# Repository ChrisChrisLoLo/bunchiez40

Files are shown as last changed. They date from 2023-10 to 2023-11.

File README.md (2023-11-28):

# bunchiez40
An experimental ultraportable keyboard that uses mouse switches to achieve a compact form factor while still being viable as a daily use keyboard. Board can be hand soldered, and case can be 3D printed or CNC'd.

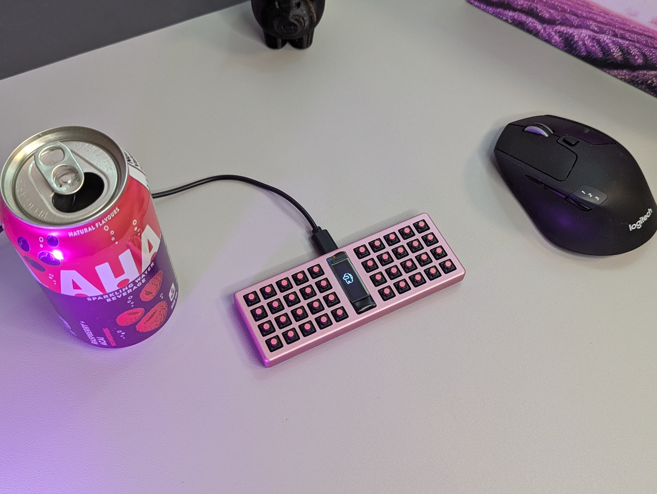
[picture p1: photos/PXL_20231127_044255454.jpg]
a photo of a bunchiez40


Has science gone too far?

# Status
v0.0 PCBs confirmed to be working! Happy to open up this project for others to play with

# About
I hit the limit as how small I could go with choc switches. I found that kailh mute switches are an ideal small form factor alternative in terms of their size, durability, and actuation force. To make this board more accessible to build at home, it uses a rp2040-zero board that can be soldered on.

More details about my research on mouse switches and experience with the bunchiez40 can be found here: https://chrischrislolo.github.io/orthoLabLogs/bunchiez40-how-i-built-a-keyboard-using-mouse-switches.html

Case files include STLs, STEP files, as well as source OpenSCAD files that can be modified. The OpenSCAD models do not have fillets on them

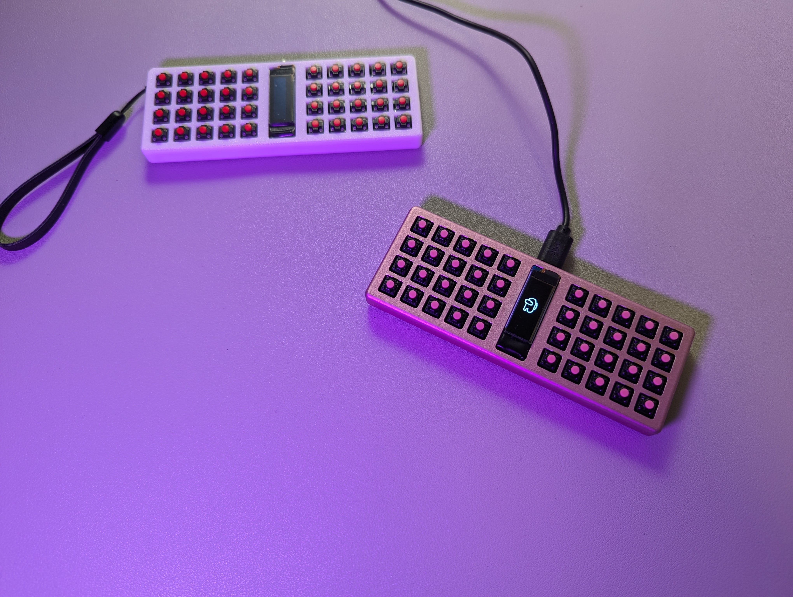
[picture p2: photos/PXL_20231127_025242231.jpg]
some bunchiez40


# Case
The case files can be found in the `case` directory. The particular files you'll want are the `case_holes` file for the top part of the case, and the `case_holes_floor` file for the bottom part. CNC and 3DP works with the top part of the case, and I chose to 3DP my case bottom.

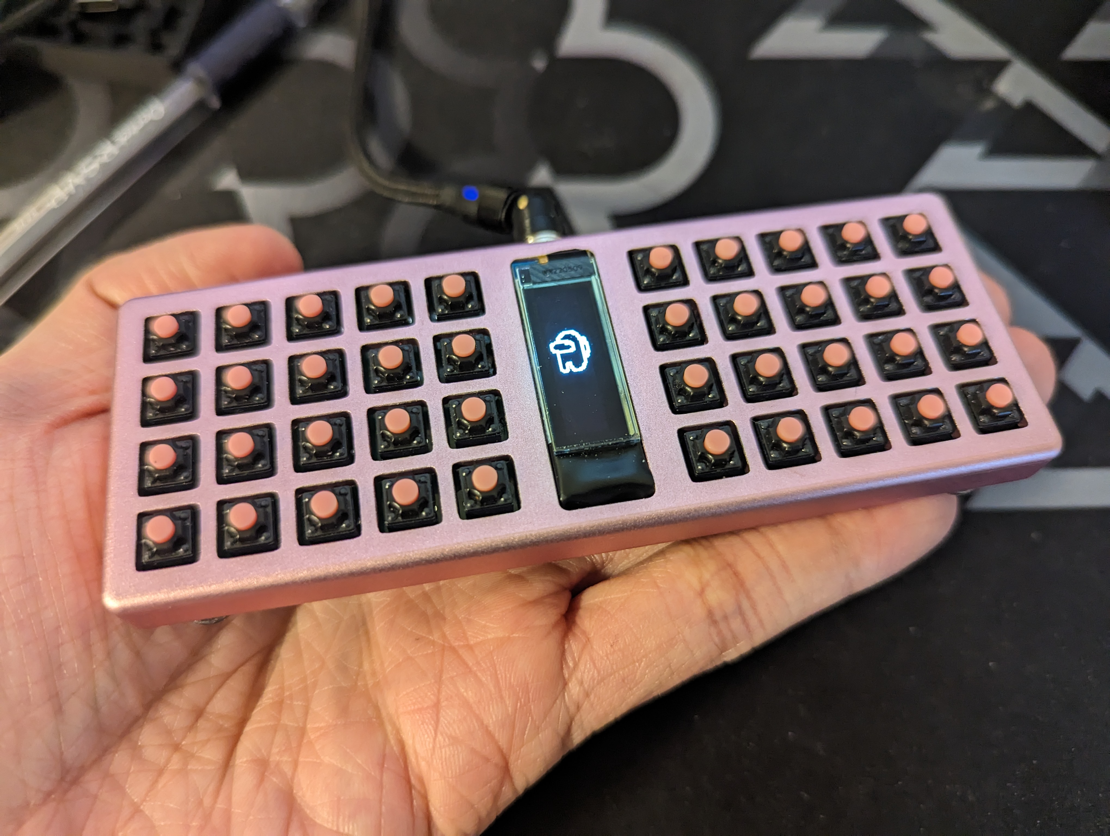
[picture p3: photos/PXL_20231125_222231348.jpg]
bunchiez40 in my hand


## PCB
You can find the PCB source files in the `pcb` folder. The BOM files can be found in this folder.

## Directory Structure
- `case`
    You can find the files you need in this folder to print out a case for the keyboard
- `drafts`
    Stores any KLE or intermediate information used in making the case
- `outlines`
    Outlines used to create the case and pcb
- `pcb`
    Kicad project relating to the project
   
## BOM
- 1 PCB
- 1 Aluminum CNC upper case or 3DP upper case
- 1 lower case. I 3D printed mine
- 16 3mm M1.6 screws (go for flathead for a flush fit, though other head types should also work)
- 4-8 (ideally 8) 1-2mm bumpons (something like Sj5302 is a good place to start)
- 1 0.91 inch OLED
- 1 rp2040-zero pcb
- 40 Kailh/Huano 7.3mm mute switches (ideally with some spares)
- 40 LL4148 diodes (ideally with some spares)

## Assembly
Build guide coming soon. For now, hopefully the footprints make it clear as to what should go where. Note that the rp2040-zero should be placed in such a way that the MCU is on "top" of the pcb when the assembly is face up, like such.
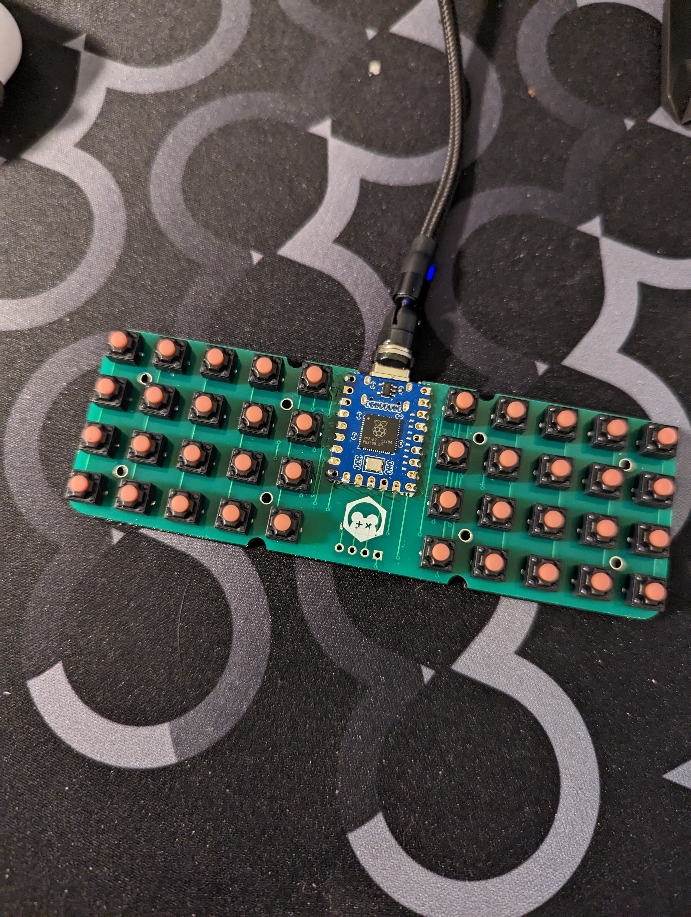
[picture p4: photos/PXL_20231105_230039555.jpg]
photo of assembly


Once all parts have been assembled, the board can be screwed onto the top of the case with 8 screws.

The firmware should then be flashed onto the board.

The bottom of the board can then be screwed to the case. My recommendation is to put two bumpons on each corner of the bottom of the case, one above the screw and one beside the screw. This helps maximize stability.  

## Firmware
QMK Firmware can be found here
https://github.com/ChrisChrisLoLo/vial-qmk/tree/sporewoh/keyboards/sporewoh/bunchiez40

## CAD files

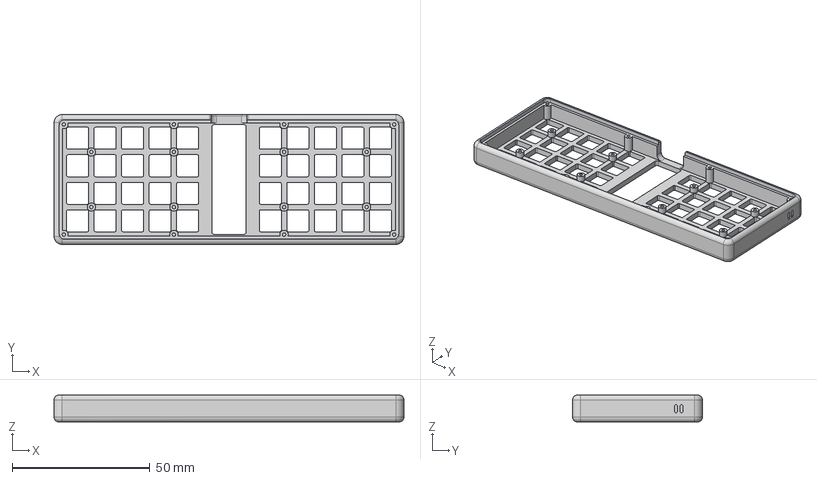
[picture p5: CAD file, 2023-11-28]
case/bunchiez40 v10.step
127.2 x 47.2 x 9.80 mm

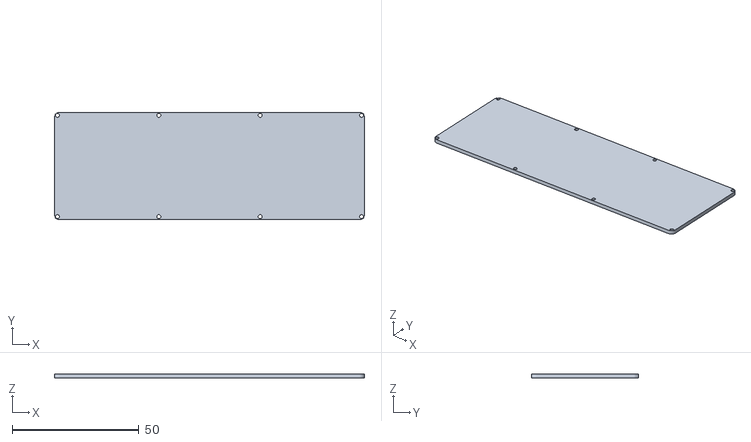
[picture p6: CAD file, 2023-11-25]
case/experimental_junk/case_bottom.stl
122.3 x 42.3 x 1.57

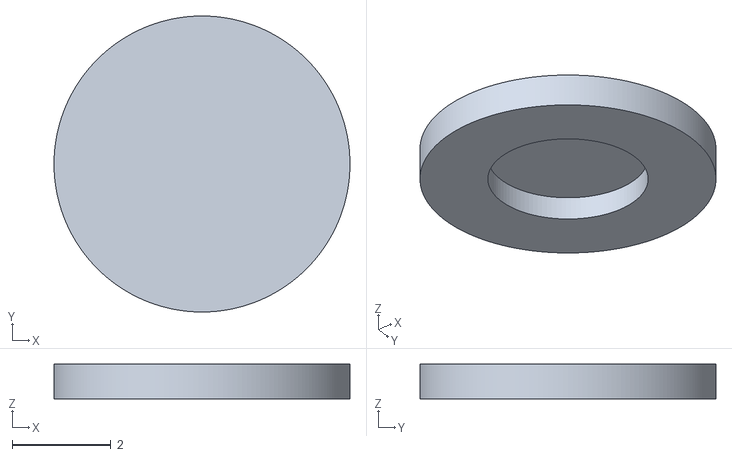
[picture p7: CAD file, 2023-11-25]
case/keys/keycap.stl
6.00 x 6.00 x 0.7

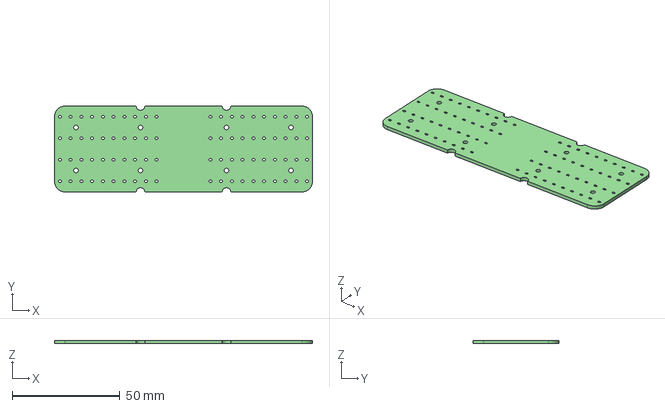
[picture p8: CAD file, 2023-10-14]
pcb/buinchiez40/buinchiez40.step
120.0 x 40.0 x 1.60 mm

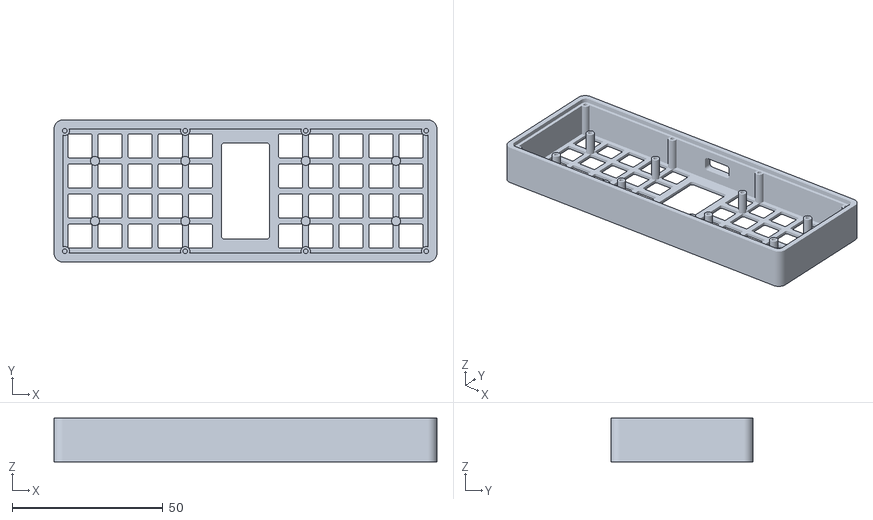
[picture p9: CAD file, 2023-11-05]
case/experimental_junk/case_holes_membrane_case.stl
127.2 x 47.2 x 14.6

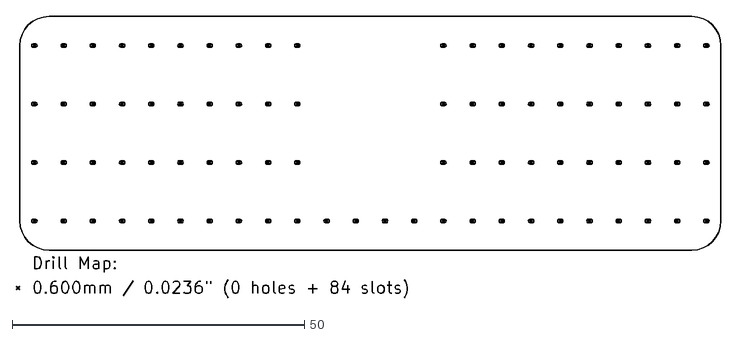
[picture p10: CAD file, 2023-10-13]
pcb/buinchiez40/buinchiez40-PTH-drl-drl_map.dxf
120.7 x 48.1

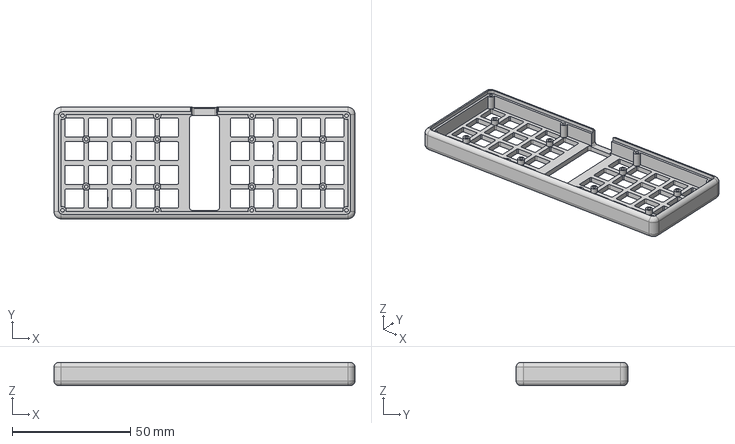
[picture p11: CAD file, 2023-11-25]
case/case_holes_top.step
127.2 x 47.2 x 9.80 mm

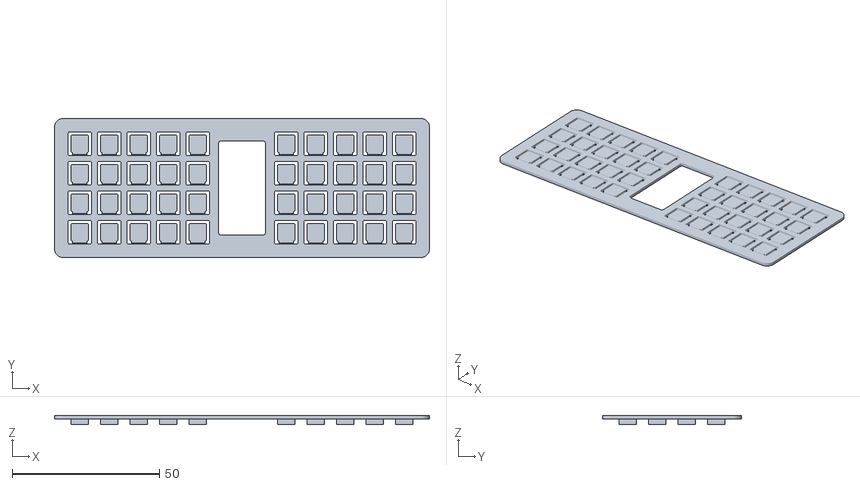
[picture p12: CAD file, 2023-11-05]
case/experimental_junk/case_hinge.stl
127.2 x 47.2 x 3.00

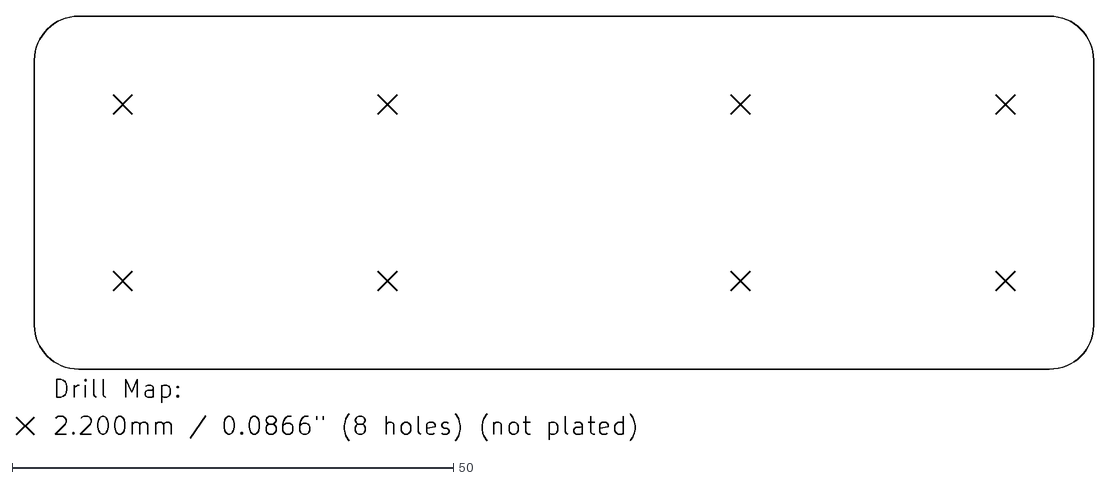
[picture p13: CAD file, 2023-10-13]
pcb/buinchiez40/buinchiez40-NPTH-drl-drl_map.dxf
122.0 x 48.1

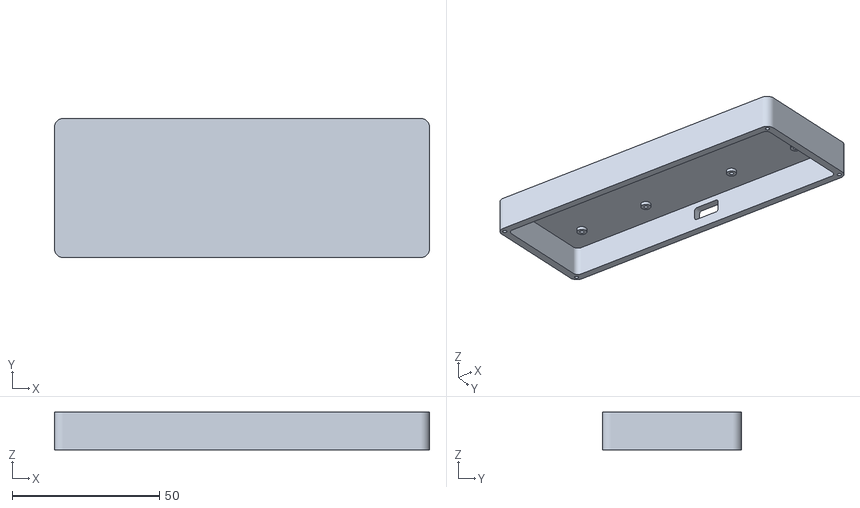
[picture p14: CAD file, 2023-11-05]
case/experimental_junk/case_hinge_bottom.stl
127.2 x 47.2 x 12.8

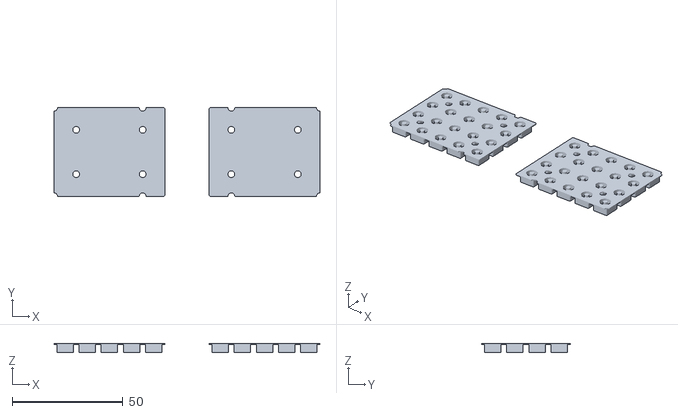
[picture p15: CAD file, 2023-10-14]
case/experimental_junk/case_holes_membrane_sheet.stl
120.0 x 40.0 x 4.00

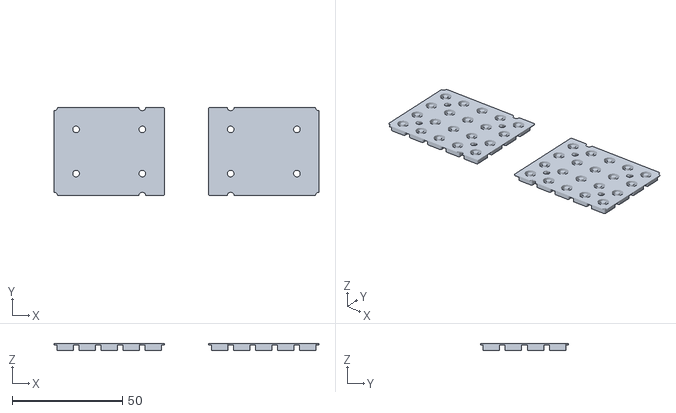
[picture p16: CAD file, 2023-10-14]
case/experimental_junk/case_holes_membrane.stl
120.0 x 40.0 x 3.00

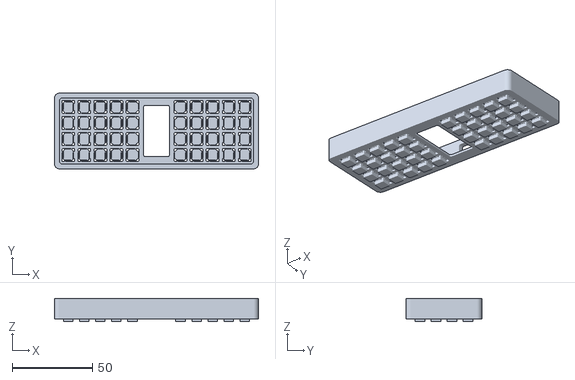
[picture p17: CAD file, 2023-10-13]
case/experimental_junk/case_spring.stl
127.2 x 47.2 x 14.6

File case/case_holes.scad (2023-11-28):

// units are in mm

$fa = 0.1;
$fs = 0.1;

//// MODULES 
module rounding2d(r) {
    offset(r = r) offset(delta = -r) children(0);
}

module fillet2d(r) {
    offset(r = -r) offset(delta = r) children(0);
}

function filletDepth(r, d, i) = r * cos(asin(d * i / r));

module topBottomFillet(b = 0, t = 2, r = 1, s = 4, e = 1) {
    if (e == 1) {        
        topFilletPeice(t = t, r = r, s = s) children(0);
        bottomFilletPeice(b = b, r = r, s = s) children(0);
        
        render()
        difference() {
            children(0);
            
            translate([0, 0, t - r])
            linear_extrude(r + 1)
            offset(delta = 1e5)
            projection()
            children(0);
            
            translate([0, 0, b - 1])
            linear_extrude(r + 1)
            offset(delta = 1e5)
            projection()
            children(0);
            
        }
    }
    if (e == 0) children(0);
}

module topFillet(t = 2, r = 1, s = 4, e = 1) {
    if (e == 1) {
        topFilletPeice(t = t, r = r, s = s) children(0);
        
        render()
        difference() {
            children(0);
            translate([0, 0, t-r])
            linear_extrude(r + 1)
            offset(delta = 1e5)
            projection()
            children(0);
        }
    }
    if (e == 0) children(0);
}

module bottomFillet(b = 0, r = 1, s = 4, e = 1) {
    if (e == 1) {
        bottomFilletPeice(b = b, r = r, s = s) children(0);
        
        render()
        difference() {
            children(0);
            translate([0, 0, b - r - 1])
            linear_extrude(r + 1)
            offset(delta = 1e5)
            projection()
            children(0);
        }
    }
    if (e == 0) children(0);
}

module topFilletPeice(t = 2, r = 1, s = 4) {
    d = r/s;
        
    for (i = [0:s]) {
        x = filletDepth(r, d, i);
        z = d * (s - i + 1);                  
        translate([0, 0, t - z]) 
        linear_extrude(d) 
        offset(delta = -r + x) 
        projection(true) 
        translate([0, 0, -t + z])
        children(0);
    }
}

module bottomFilletPeice(b = 0, r =1, s = 4) {
    d = r/s;
        
    for (i = [0:s]) {
        x = filletDepth(r, d, i);
        z = d * (s - i);
        translate([0, 0, b + z]) 
        linear_extrude(d) 
        offset(delta = -r + x) 
        projection(true)
        translate([0, 0, b - z])
        children(0);
    }
}


//// CONSTANTS
// Choc spacing dimensions
KEY_LENGTH = 10;
KEY_WIDTH = 10;

// Choc plate cutout dimensions
KEY_CUTOUT_X = 8;
KEY_CUTOUT_Y = KEY_CUTOUT_X;
KEY_CUTOUT_RADIUS = 0.5;

// Case constants
INNER_FILLET_RADIUS = 2.0; // internal fillet
OUTER_FILLET_RADIUS = 3.0; // external fillet
CORNER_FILLET_RADIUS = 1.0; // use to round out case

FLOOR_LIP_LENGTH = 1.1;

WALL_MARGIN = 0.3; // gap between pcb and case for one side
PCB_TOLERANCE = 0.3 + WALL_MARGIN; // accounts for pcb cutout tolerance

TOTAL_WALL_WIDTH = 3.0;
INNER_WALL_WIDTH = FLOOR_LIP_LENGTH;
OUTER_WALL_WIDTH = TOTAL_WALL_WIDTH - INNER_WALL_WIDTH;

NUM_KEYS_X = 12;
NUM_KEYS_Y = 4;

// Dimensions
PCB_LENGTH = KEY_LENGTH * NUM_KEYS_X;
PCB_WIDTH = KEY_WIDTH * NUM_KEYS_Y;

CASE_INNER_LENGTH = PCB_LENGTH + (PCB_TOLERANCE*2);
CASE_INNER_WIDTH = PCB_WIDTH + (PCB_TOLERANCE*2);

CASE_INNER_WALL_LENGTH = CASE_INNER_LENGTH + (INNER_WALL_WIDTH*2);
CASE_INNER_WALL_WIDTH = CASE_INNER_WIDTH + (INNER_WALL_WIDTH*2);

CASE_OUTER_WALL_LENGTH = CASE_INNER_WALL_LENGTH + (OUTER_WALL_WIDTH*2);
CASE_OUTER_WALL_WIDTH = CASE_INNER_WALL_WIDTH + (OUTER_WALL_WIDTH*2);

PLATE_HEIGHT = 2.2; // 1.2; // Height of the integrated plate
FLOOR_HEIGHT = 1.6; // Height of the PCB bottom
CASE_UPPER_HEIGHT = 0; // Height of the wall above the plate
CASE_INNER_WALL_HEIGHT = PLATE_HEIGHT+6; //TODO; can probably be lower
CASE_OUTER_WALL_HEIGHT = CASE_INNER_WALL_HEIGHT+FLOOR_HEIGHT+CASE_UPPER_HEIGHT; // Height of the outer case
SCREW_POLE_HEIGHT = CASE_INNER_WALL_HEIGHT;
// no holes
SCREW_POLE_INNER_HEIGHT = SCREW_POLE_HEIGHT - 3.5;

SCREW_POLE_OUTER_RADIUS = 3.1/2;
SCREW_POLE_INNER_RADIUS = 1.3/2;

// Modules
module case_inner_square(height, corner_radius) {
    linear_extrude(height)
        rounding2d(corner_radius)
        square([CASE_INNER_LENGTH,CASE_INNER_WIDTH], center = true);
}

module case_inner_wall_square(height, corner_radius) {
    linear_extrude(height)
        rounding2d(corner_radius)
        square([CASE_INNER_WALL_LENGTH,CASE_INNER_WALL_WIDTH], center = true);
}

module case_outer_wall_square(height, corner_radius) {
    translate([0,0,-CASE_UPPER_HEIGHT])
        linear_extrude(height)
        rounding2d(corner_radius)
        square([CASE_OUTER_WALL_LENGTH,CASE_OUTER_WALL_WIDTH], center = true);
}

module key_cutout_square() {
    linear_extrude(PLATE_HEIGHT+0.01)
        rounding2d(KEY_CUTOUT_RADIUS)
        square([KEY_CUTOUT_X,KEY_CUTOUT_Y], center = true);
}

module key_flexture(key_x, key_y, key_difference, spring_thickness) {
    base_thickness = 0; // base thickness is used to give more strength for the base

    linear_extrude(0.2)
        union(){
            // NOTE: springs should be turned into a module
            // towards key
            translate([-KEY_CUTOUT_X/4,(+key_y/2)+((key_difference/2)/2)+(spring_thickness/2),0])
                square([spring_thickness+base_thickness, key_difference/2], center = true);
            translate([+KEY_CUTOUT_X/4,(+key_y/2)+((key_difference/2)/2)+(spring_thickness/2),0])
                square([spring_thickness+base_thickness, key_difference/2], center = true);
            // towards cutout
            translate([+KEY_CUTOUT_X/4,(+key_y/2)+((key_difference/2)/2)-(spring_thickness/2),0])
                square([spring_thickness, key_difference/2], center = true);
            translate([-KEY_CUTOUT_X/4,(+key_y/2)+((key_difference/2)/2)-(spring_thickness/2),0])
                square([spring_thickness, key_difference/2], center = true);
            // re-enforcement
            
            translate([0,(+key_y/2)+0.2,0])
                square([key_x-1.5, 0.5], center = true);
        };
    
    // tab on key to prevent it from lifting out of the case
    tab_thickness = 0.5;
    translate([0,(-key_y/2),0.7])
        linear_extrude(tab_thickness)
        square([5,1.4], center = true);
        
    tab_thickness = 0.5;
    translate([0,(-key_y/2)-(key_difference/2)])
        linear_extrude(tab_thickness)
        
        square([5,1.4], center = true);
}

module key_square() {
    spring_thickness = 0.5;
    key_height = 3;
    key_difference = 2;
    key_x = KEY_CUTOUT_X-key_difference;
    key_y = KEY_CUTOUT_Y-key_difference;
    union(){
        translate([0,0,-key_height+PLATE_HEIGHT])
            union(){
                linear_extrude(key_height)
                    rounding2d(KEY_CUTOUT_RADIUS)
                    square([key_x,key_y], center = true);
            };
        key_flexture(key_x, key_y, key_difference, spring_thickness);
    }
}

module key_cutout_matrix() {
    for (i = [0:NUM_KEYS_X-1]){
        for (j = [0:NUM_KEYS_Y-1]){
            if (i!=5 && i!=6){ // We don't want key cutouts on the middle cols
                translate([KEY_LENGTH*(i-((NUM_KEYS_X/2)-0.5)),KEY_WIDTH*(j-(NUM_KEYS_Y/2)+0.5),0])
                    key_cutout_square();
            }    
        }
    }
}

module key_matrix(){
    for (i = [0:NUM_KEYS_X-1]){
        for (j = [0:NUM_KEYS_Y-1]){
            if (i!=5 && i!=6){ // We don't want key cutouts on the middle cols
                translate([KEY_LENGTH*(i-((NUM_KEYS_X/2)-0.5)),KEY_WIDTH*(j-(NUM_KEYS_Y/2)+0.5),0])
                    key_square();
            }    
        }
    }
}

module key_silicone() {
    
}

module key_silicone_matrix(){
    for (i = [0:NUM_KEYS_X-1]){
        for (j = [0:NUM_KEYS_Y-1]){
            if (i!=5 && i!=6){ // We don't want key cutouts on the middle cols
                translate([KEY_LENGTH*(i-((NUM_KEYS_X/2)-0.5)),KEY_WIDTH*(j-(NUM_KEYS_Y/2)+0.5),0])
                    key_square();
            }    
        }
    }
}

module screw_pole() {
    difference(){
        linear_extrude(SCREW_POLE_HEIGHT)
            circle(SCREW_POLE_OUTER_RADIUS);
        screw_hole();
    }
}

module screw_hole() {
    height_diff = SCREW_POLE_HEIGHT-SCREW_POLE_INNER_HEIGHT;

    translate([0,0,height_diff])
    linear_extrude(SCREW_POLE_INNER_HEIGHT)
        circle(SCREW_POLE_INNER_RADIUS);
}

module screw_pole_matrix() {
    for (i = [0:NUM_KEYS_X]){
        for (j = [0:NUM_KEYS_Y]){
            if (
                (i==0  && j==0)  ||
                (i==0  && j==4)  ||
                (i==4  && j==0)  ||
                (i==4  && j==4)  ||
                (i==8  && j==0)  ||
                (i==8  && j==4)  ||
                (i==12  && j==0) ||
                (i==12  && j==4)  
            ){
                translate([KEY_LENGTH*(i-((NUM_KEYS_X/2))),KEY_WIDTH*(j-(NUM_KEYS_Y/2)),0])
                    screw_pole();
            }    
        }
    }
}
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

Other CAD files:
case/case_holes.stl
case/case_holes_bottom.step
case/experimental_junk/case_hinge_top.stl
pcb/buinchiez40/pcb_prototype.stl
case/experimental_junk/case_holes_floor.stl
case/experimental_junk/case.scad
case/experimental_junk/case_circle_flexure.scad
case/experimental_junk/case_hinge.scad
case/experimental_junk/case.stl
case/experimental_junk/case_holes_membrane.scad
case/experimental_junk/case_v2.stl
case/experimental_junk/keycaps.stl
case/keys/keycap.scad

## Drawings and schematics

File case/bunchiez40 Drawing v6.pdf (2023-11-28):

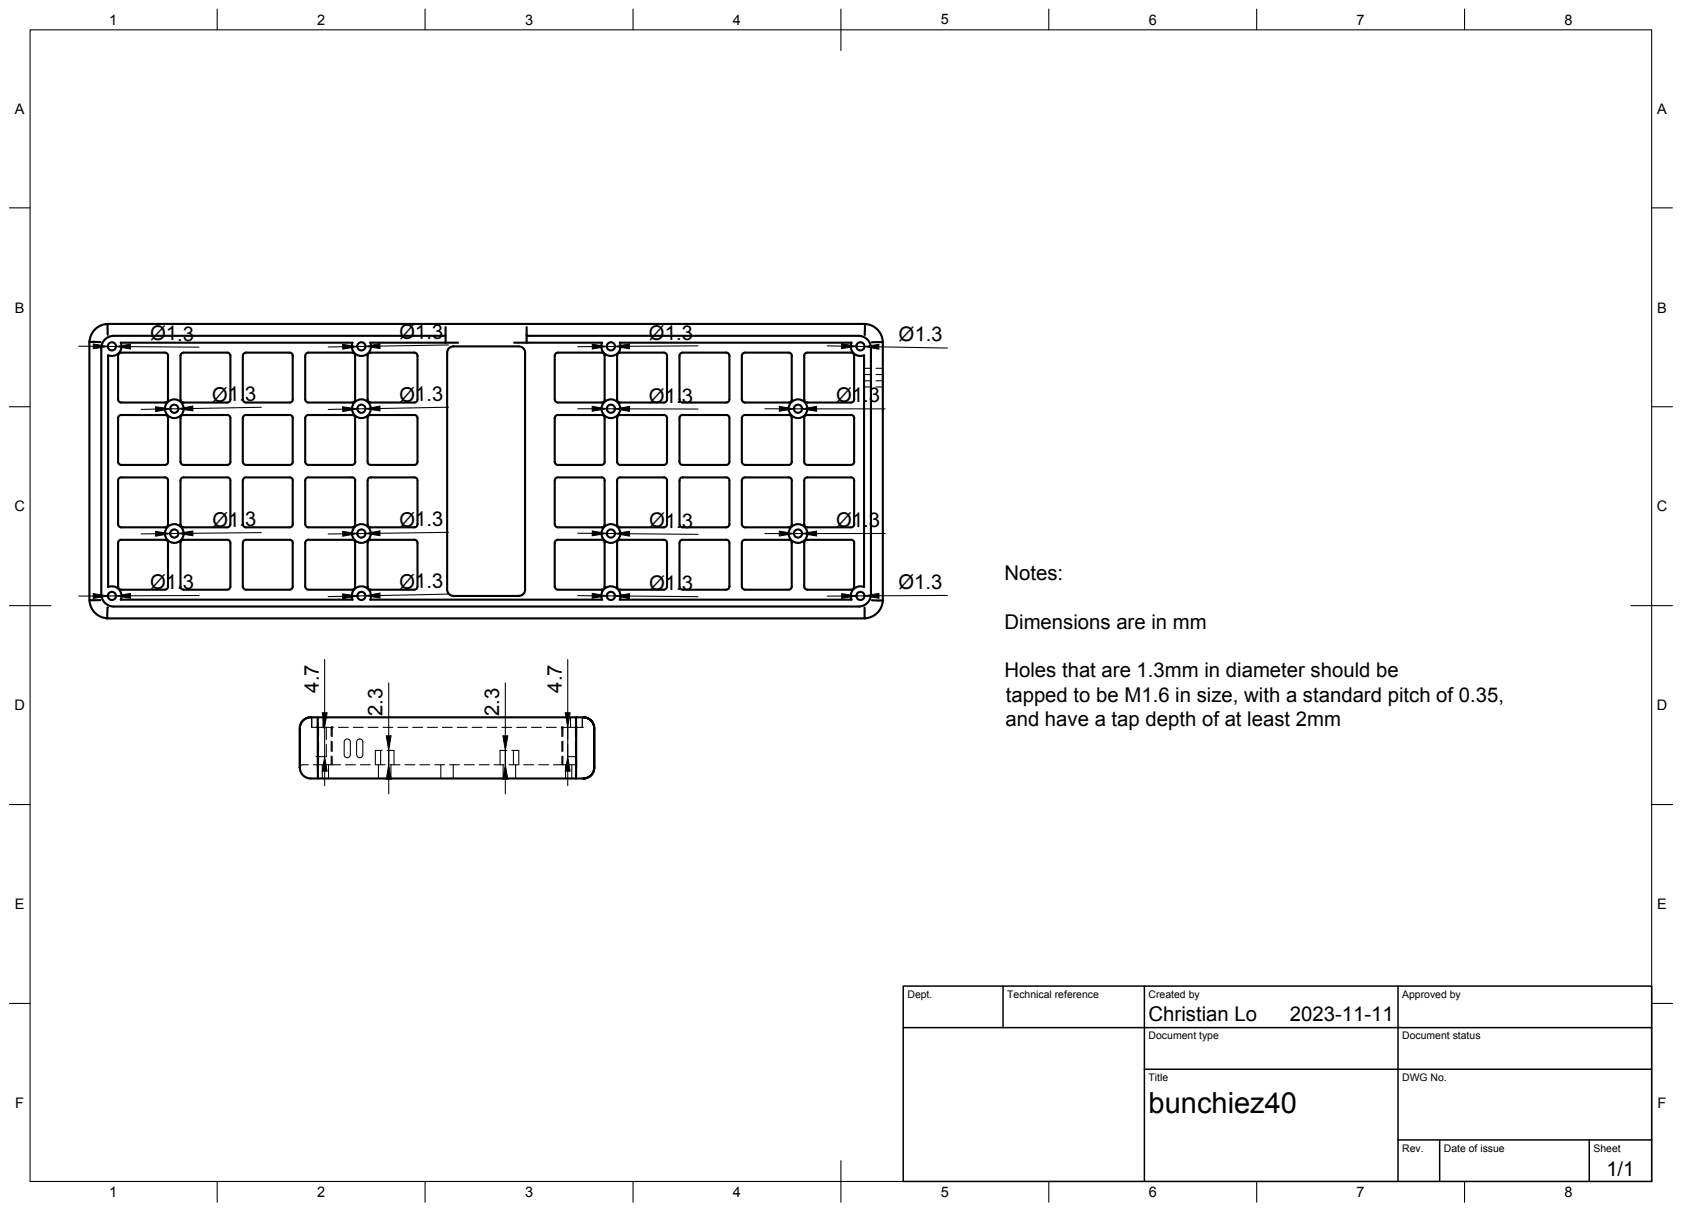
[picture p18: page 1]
Title; DWG No.; Rev.; Date of issue; Sheet

Dimensions are in mm

Holes that are 1.3mm in diameter should be
tapped to be M1.6 in size, with a standard pitch of 0.35,
and have a tap depth of at least 2mm

Dept. | Technical reference | Created by Christian Lo 2023-11-11 | Approved by

Document type | Document status

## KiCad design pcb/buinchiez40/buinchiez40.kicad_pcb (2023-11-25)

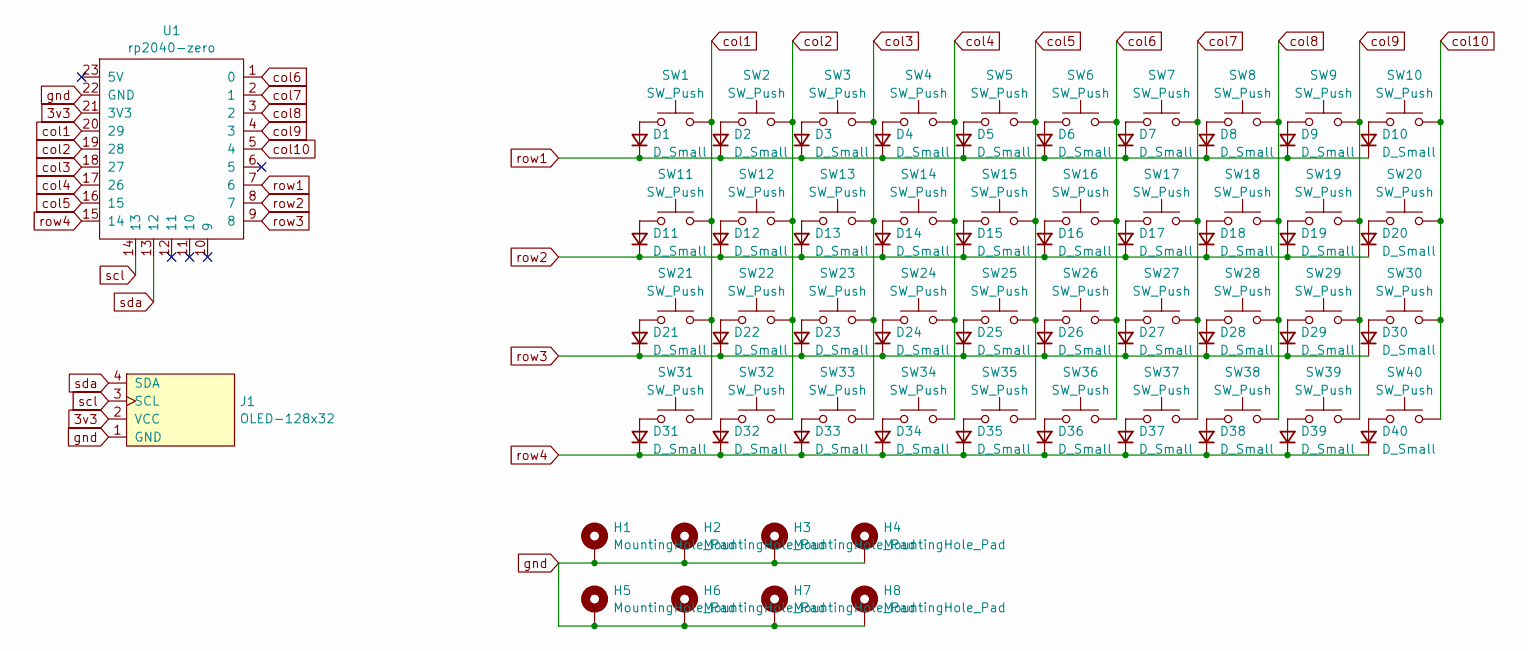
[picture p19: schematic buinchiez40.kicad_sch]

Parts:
D1, D2, D3, D4, D5, D6, D7, D8, D9, D10, D11, D12, D13, D14, D15, D16, D17, D18, D19, D20, D21, D22, D23, D24, D25, D26, D27, D28, D29, D30, D31, D32, D33, D34, D35, D36, D37, D38, D39, D40: D_Small; D_MiniMELF
H1, H2, H3, H4, H5, H6, H7, H8: MountingHole_Pad; m1.6_hole
J1: OLED-128x32; OLED-128x32-cutout
SW1, SW2, SW3, SW4, SW5, SW6, SW7, SW8, SW9, SW10, SW11, SW12, SW13, SW14, SW15, SW16, SW17, SW18, SW19, SW20, SW21, SW22, SW23, SW24, SW25, SW26, SW27, SW28, SW29, SW30, SW31, SW32, SW33, SW34, SW35, SW36, SW37, SW38, SW39, SW40: SW_Push; Button_Mute_Kailh
U1: rp2040-zero; rp2040-zero-tht

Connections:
3v3: J1.2 (VCC), U1.21 (3V3)
unnamed: D1.2 (A), SW1.1
unnamed: D2.2 (A), SW2.1
unnamed: D3.2 (A), SW3.1
unnamed: D4.2 (A), SW4.1
unnamed: D5.2 (A), SW5.1
unnamed: D6.2 (A), SW6.1
unnamed: D7.2 (A), SW7.1
unnamed: D8.2 (A), SW8.1
unnamed: D9.2 (A), SW9.1
unnamed: D10.2 (A), SW10.1
unnamed: D11.2 (A), SW11.1
unnamed: D12.2 (A), SW12.1
unnamed: D13.2 (A), SW13.1
unnamed: D14.2 (A), SW14.1
unnamed: D15.2 (A), SW15.1
unnamed: D16.2 (A), SW16.1
unnamed: D17.2 (A), SW17.1
unnamed: D18.2 (A), SW18.1
unnamed: D19.2 (A), SW19.1
unnamed: D20.2 (A), SW20.1
unnamed: D21.2 (A), SW21.1
unnamed: D22.2 (A), SW22.1
unnamed: D23.2 (A), SW23.1
unnamed: D24.2 (A), SW24.1
unnamed: D25.2 (A), SW25.1
unnamed: D26.2 (A), SW26.1
unnamed: D27.2 (A), SW27.1
unnamed: D28.2 (A), SW28.1
unnamed: D29.2 (A), SW29.1
unnamed: D30.2 (A), SW30.1
unnamed: D31.2 (A), SW31.1
unnamed: D32.2 (A), SW32.1
unnamed: D33.2 (A), SW33.1
unnamed: D34.2 (A), SW34.1
unnamed: D35.2 (A), SW35.1
unnamed: D36.2 (A), SW36.1
unnamed: D37.2 (A), SW37.1
unnamed: D38.2 (A), SW38.1
unnamed: D39.2 (A), SW39.1
unnamed: D40.2 (A), SW40.1
col1: SW1.2, SW11.2, SW21.2, SW31.2, U1.20 (29)
col2: SW2.2, SW12.2, SW22.2, SW32.2, U1.19 (28)
col3: SW3.2, SW13.2, SW23.2, SW33.2, U1.18 (27)
col4: SW4.2, SW14.2, SW24.2, SW34.2, U1.17 (26)
col5: SW5.2, SW15.2, SW25.2, SW35.2, U1.16 (15)
col6: SW6.2, SW16.2, SW26.2, SW36.2, U1.1 (0)
col7: SW7.2, SW17.2, SW27.2, SW37.2, U1.2 (1)
col8: SW8.2, SW18.2, SW28.2, SW38.2, U1.3 (2)
col9: SW9.2, SW19.2, SW29.2, SW39.2, U1.4 (3)
col10: SW10.2, SW20.2, SW30.2, SW40.2, U1.5 (4)
gnd: H1.1, H2.1, H3.1, H4.1, H5.1, H6.1, H7.1, H8.1, J1.1 (GND), U1.22 (GND)
row1: D1.1 (K), D2.1 (K), D3.1 (K), D4.1 (K), D5.1 (K), D6.1 (K), D7.1 (K), D8.1 (K), D9.1 (K), D10.1 (K), U1.7 (6)
row2: D11.1 (K), D12.1 (K), D13.1 (K), D14.1 (K), D15.1 (K), D16.1 (K), D17.1 (K), D18.1 (K), D19.1 (K), D20.1 (K), U1.8 (7)
row3: D21.1 (K), D22.1 (K), D23.1 (K), D24.1 (K), D25.1 (K), D26.1 (K), D27.1 (K), D28.1 (K), D29.1 (K), D30.1 (K), U1.9 (8)
row4: D31.1 (K), D32.1 (K), D33.1 (K), D34.1 (K), D35.1 (K), D36.1 (K), D37.1 (K), D38.1 (K), D39.1 (K), D40.1 (K), U1.15 (14)
scl: J1.3 (SCL), U1.14 (13)
sda: J1.4 (SDA), U1.13 (12)

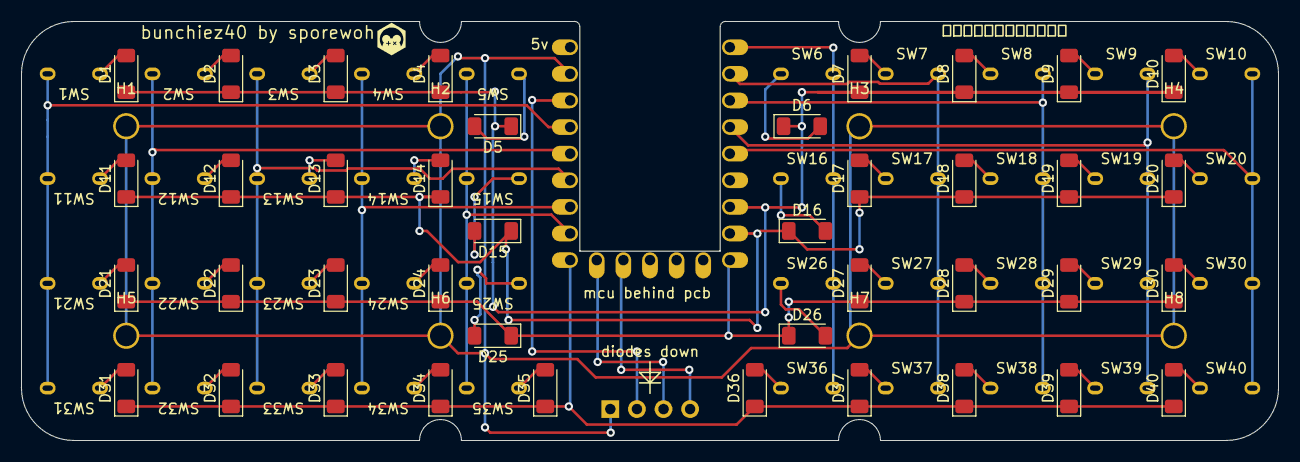
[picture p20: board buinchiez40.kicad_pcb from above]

Board: 2 copper layers, 120.0 x 40.0 mm, 90 parts (1 on the bottom side), 58 nets.

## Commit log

2023-10-13 add case
    [buinchiez40-NPTH-drl-drl_map.dxf, buinchiez40-PTH-drl-drl_map.dxf, buinchiez40.kicad_pcb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]
2023-10-14 add case iterations
    [buinchiez40.kicad_pcb, buinchiez40.step, case_hinge.scad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]
2023-10-14 add membrane
    [case_holes_membrane.scad, case_holes_membrane.stl, case_holes_membrane_sheet.stl]
2023-10-15 add and export pcb
2023-11-05 add pcb output and cases
    [buinchiez40-B_Cu.gbr, buinchiez40-B_Mask.gbr, buinchiez40-B_Paste.gbr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]
2023-11-25 add grounding pads
    [buinchiez40-B_Cu.gbr, buinchiez40-B_Mask.gbr, buinchiez40-B_Paste.gbr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]
2023-11-28 add drawings and photos
    [bunchiez40 v10.step, case_holes.scad]
2023-11-28 reorganize CAD files
    [bunchiez40 v2.step, bunchiez40 v5.dxf, bunchiez40 v6.step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]
